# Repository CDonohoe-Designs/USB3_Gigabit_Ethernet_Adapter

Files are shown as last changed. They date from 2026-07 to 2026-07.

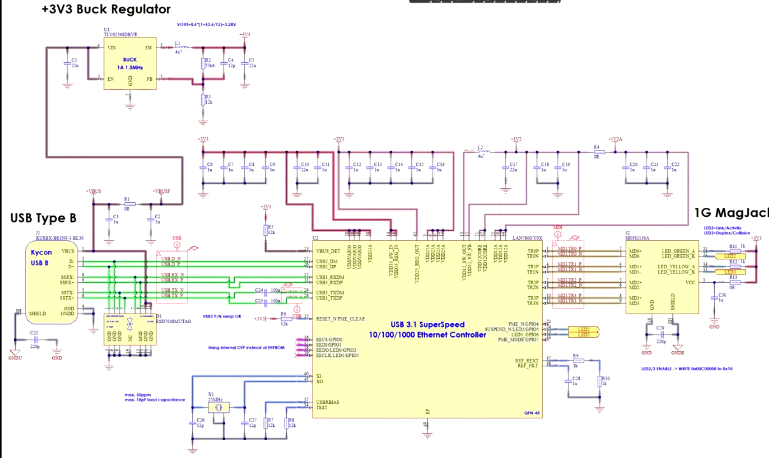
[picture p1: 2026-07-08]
Images/Schematic/Schematic_PMS.PNG

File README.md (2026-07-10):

# USB3 Gigabit Ethernet Adapter

## Project Overview

This repository documents the hardware design and PCB development of a **USB 3.1 Gen 1 to Gigabit Ethernet adapter** based on the **Microchip LAN7800 USB-to-Ethernet controller**.

The project is being developed in **Altium Designer** as a complete hardware design and PCB layout exercise.

The design work includes:

- Schematic capture and hierarchical design structure
- Component selection
- USB 2.0 and USB 3 SuperSpeed interfaces
- Gigabit Ethernet MDI interface
- Power-tree design and decoupling
- ESD protection
- Controlled-impedance PCB routing
- Differential-pair routing and length matching
- PCB design-rule definition
- Design for Manufacture (DFM)
- Design for Test (DFT)
- Manufacturing outputs
- Board bring-up and validation planning

---

## Project Goals

- Design a LAN7800-based USB 3.1 Gen 1 to Gigabit Ethernet adapter in Altium Designer.
- Select and justify the main components used in the design.
- Create a structured schematic covering USB, power, LAN7800, Ethernet, ESD protection, LEDs, reset and test points.
- Implement a four-layer PCB architecture suitable for USB 3 and Gigabit Ethernet routing.
- Define controlled-impedance and differential-pair PCB design rules.
- Route the USB 3 SuperSpeed, USB 2.0 and Gigabit Ethernet interfaces.
- Prepare manufacturing outputs including Gerbers, drill files, BOM, pick-and-place files and schematic PDFs.
- Document the board bring-up and validation process.

---

## Project Documentation

### Schematic

- [LAN7800 USB Ethernet Schematic PDF](Hardware/Altium/LAN7800_USB_Ethernet_RevA/LAN7800_USB_Ethernet_RevA_Schematic.pdf)

### Engineering Documentation

- [Documentation Folder](Docs/)
- [Design Requirements](Docs/01_Design_Requirements.md)
- [Component Selection](Docs/02_Component_Selection.md)
- [PCB Architecture and Stack-Up](Docs/03_PCB_Architecture_and_Stackup.md)

---

## Design Status

| Area | Status |
|---|---|
| Repository structure | Complete |
| Project requirements | Complete |
| Component selection | Complete |
| Schematic design | Complete |
| PCB architecture and stack-up | Complete |
| PCB design rules | Complete |
| Component placement | In progress |
| USB differential-pair routing | In progress |
| Ethernet differential-pair routing | Not started |
| General PCB routing | Not started |
| Manufacturing outputs | Not started |
| Bring-up plan | Not started |

---

## Main IC

**Microchip LAN7800**

USB 3.1 Gen 1 to 10/100/1000 Gigabit Ethernet controller.

The LAN7800 provides the bridge between the USB interface and the Gigabit Ethernet PHY.

---

## Design Sections

The hardware design contains the following main functional areas:

- USB 3.0 Type-B interface
- USB 2.0 D+ / D− interface
- USB 3 SuperSpeed TX and RX differential pairs
- LAN7800 controller
- Gigabit Ethernet MDI interface
- RJ45 connector and magnetics
- USB VBUS input filtering
- 3.3 V power regulation
- LAN7800 2.5 V and 1.2 V supply rails
- 25 MHz crystal and clock circuitry
- Reset and configuration straps
- Ethernet status LEDs
- USB and Ethernet ESD protection
- Power, reset and bring-up test points

---

## PCB Architecture

The design uses a **4-layer PCB stack-up**.

| Layer | Function |
|---|---|
| L1 – Top | Components, USB, Ethernet and critical signals |
| L2 – GND | Continuous high-speed signal reference plane |
| L3 – GND | Secondary continuous ground plane |
| L4 – Bottom | Power distribution and secondary routing |

USB and Ethernet high-speed differential pairs are routed primarily on the Top Layer and referenced to the continuous L2 ground plane.

The PCB design includes controlled-impedance profiles for:

- USB 2.0 — 90 Ω differential
- USB 3 SuperSpeed — 90 Ω differential
- Gigabit Ethernet MDI — 100 Ω differential

---

## PCB Design Rules

The Altium project includes dedicated design constraints for:

- USB 2.0 differential routing
- USB 3 SuperSpeed differential routing
- Gigabit Ethernet differential routing
- Differential-pair clearance
- Pair-to-pair Ethernet spacing
- USB 3 clearance from unrelated signals
- Power-rail trace widths
- Switching-node routing
- Via dimensions
- Annular ring requirements
- Solder-mask expansion
- Solder-mask sliver
- Silkscreen-to-mask clearance
- Differential-pair length matching

The routing constraints and impedance geometry are derived from the implemented Altium four-layer stack-up.

---

## Repository Structure

```text
USB3_Gigabit_Ethernet_Adapter/
│
├── Docs/
│   ├── 01_Design_Requirements.md
│   ├── 02_Component_Selection.md
│   └── 03_PCB_Architecture_and_Stackup.md
│
├── Hardware/
│   └── Altium/
│       └── LAN7800_USB_Ethernet_RevA/
│           ├── 01_USB_B_and_Power.SchDoc
│           ├── 02_LAN7800_Controller.SchDoc
│           ├── LAN7800_USB_Ethernet_RevA.PcbDoc
│           ├── LAN7800_USB_Ethernet_RevA.PrjPcb
│           └── LAN7800_USB_Ethernet_RevA_Schematic.pdf
│
├── Libraries/
├── Assembly/
├── BOM/
├── Gerbers/
├── PDFs/
│
└── README.md

## Project Files

- [View Schematic PDF](Hardware/Altium/LAN7800_USB_Ethernet_RevA/LAN7800_USB_Ethernet_RevA_Schematic.pdf)
- [View Engineering Documentation](Docs/)
- [Browse Altium Design Files](Hardware/Altium/LAN7800_USB_Ethernet_RevA/)

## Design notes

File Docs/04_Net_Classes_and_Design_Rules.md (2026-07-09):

# PCB Net Classes and Design Rules

## 1. Purpose

This document records the electrical, routing and manufacturing constraints applied to the LAN7800 USB 3.1 Gen 1 to Gigabit Ethernet Adapter PCB.

The rules are intended to:

- Control trace widths and clearances
- Apply controlled-impedance routing
- Separate high-speed, power and general-purpose nets
- Control differential-pair geometry
- Define via and board-manufacturing constraints
- Provide traceable engineering evidence for design review

## 2. Rule-Definition Strategy

The PCB will use a hierarchical rule structure.

General rules will apply to the complete PCB, while more-specific rules will override them for:

- USB 2.0
- USB 3.x SuperSpeed
- Gigabit Ethernet MDI
- Power rails
- Crystal circuitry
- General low-speed signals

The most-specific applicable rule will be given the highest priority.

## 3. Planned Net Classes

| Net class | Function |
|---|---|
| `USB2_HS` | USB 2.0 D+ and D− |
| `USB3_SS` | USB 3.x TX and RX differential pairs |
| `ETH_MDI` | Four Gigabit Ethernet MDI pairs |
| `CLOCK_25MHZ` | LAN7800 crystal nets |
| `POWER_VBUS` | USB VBUS and filtered VBUS |
| `POWER_3V3` | 3.3 V digital and analogue rails |
| `POWER_2V5` | LAN7800 internal 2.5 V rail |
| `POWER_1V2` | LAN7800 internal 1.2 V rails |
| `GENERAL` | Remaining low-speed signals |

## 4. Differential-Pair Classes

| Differential-pair class | Members |
|---|---|
| `USB2_DIFF` | USB 2.0 differential pair |
| `USB3_DIFF` | USB 3 TX and RX pairs |
| `ETH_DIFF` | MDI TR0, TR1, TR2 and TR3 pairs |

## 5. Controlled-Impedance Profiles

| Interface | Altium profile | Target |
|---|---|---:|
| USB 2.0 | `D90` | 90 Ω differential |
| USB 3.x | `D90` | 90 Ω differential |
| Gigabit Ethernet | `D100` | 100 Ω differential |

The profiles were calculated using the implemented four-layer stack in Altium Layer Stack Manager.

## Differential-Pair Routing Rules

| Rule | Differential-pair class | Impedance profile | Width | Gap |
|---|---|---|---:|---:|
| `DP_USB3_D90` | `USB3_DIFF` | `D90` | 0.246 mm | 0.127 mm |
| `DP_USB2_D90` | `USB2_DIFF` | `D90` | 0.246 mm | 0.127 mm |
| `DP_ETH_D100` | `ETH_DIFF` | `D100` | 0.184 mm | 0.127 mm |

The preferred width and pair gap are derived from the controlled-impedance profiles in Altium Layer Stack Manager.

## Differential-Pair Clearance Rule

A dedicated clearance rule permits the controlled-impedance gap within each differential pair while maintaining a larger clearance to unrelated copper.

| Rule | Application | Minimum clearance | Priority |
|---|---|---:|---:|
| `CLEARANCE_SAME_DIFF_PAIR` | Members of the same differential pair | 0.127 mm | 1 |
| `Clearance_1` | All other electrical objects | 0.254 mm | 2 |

The differential-pair rule has higher priority than the general board-clearance rule.

## Routing Width Rules

| Rule | Scope | Minimum | Preferred | Maximum |
|---|---|---:|---:|---:|
| `WIDTH_SWITCH_NODES` | `SWITCH_NODES` | 0.40 mm | 0.60 mm | 1.00 mm |
| `WIDTH_VBUS` | `POWER_VBUS` | 0.40 mm | 0.60 mm | 1.00 mm |
| `WIDTH_1V2` | `POWER_1V2` | 0.30 mm | 0.50 mm | 0.80 mm |
| `WIDTH_3V3` | `POWER_3V3` | 0.30 mm | 0.50 mm | 0.80 mm |
| `WIDTH_2V5` | `POWER_2V5` | 0.20 mm | 0.30 mm | 0.50 mm |
| `WIDTH_GENERAL` | All remaining nets | 0.15 mm | 0.20 mm | 0.30 mm |

The values are initial routing constraints. Short power connections may use copper regions where this provides a lower-impedance current path.

## Routing Layer Rules

High-speed and clock nets are constrained to the Top Layer so that they reference the adjacent continuous L2 ground plane and avoid unnecessary layer transitions.

| Rule | Net class | Top Layer | Bottom Layer |
|---|---|---|---|
| `ROUTE_LAYER_USB3` | `USB3_SS` | Allowed | Not allowed |
| `ROUTE_LAYER_USB2` | `USB2_HS` | Allowed | Not allowed |
| `ROUTE_LAYER_ETH` | `ETH_MDI` | Allowed | Not allowed |
| `ROUTE_LAYER_CLOCK` | `CLOCK_25MHZ` | Allowed | Not allowed |
| `ROUTE_LAYER_GENERAL` | All remaining nets | Allowed | Allowed |

The high-speed interfaces will be routed primarily on L1 and referenced to the continuous L2 `GND_1` plane.

## Routing Via Style Rules

| Rule | Scope | Preferred diameter | Preferred hole |
|---|---|---:|---:|
| `VIA_POWER` | Power net classes | 0.80 mm | 0.40 mm |
| `VIA_GENERAL` | All remaining nets | 0.60 mm | 0.30 mm |

The general via provides a 0.15 mm nominal annular ring. Larger power vias are preferred where supply rails change layers. USB, Ethernet and crystal nets are constrained to the Top Layer to avoid unnecessary via transitions.

## Matched-Length Rules

This checks the overall length difference between MDI_TR0, TR1, TR2 and TR3. Microchip allows a maximum delta of 600 mils or 15.24 mm between the four pairs.

Altium uses Within Differential Pair Length for matching the two members of each pair, and Group Matched Lengths for matching complete differential pairs against one another.

| Rule | Scope | Mode | Tolerance |
| --- | --- | --- | ---: |
| `MATCH_USB3_WITHIN_PAIR`  | `USB3_DIFF` | Within differential pair |  0.127 mm |
| `MATCH_ETH_WITHIN_PAIR` | `ETH_DIFF`  | Within differential pair | 1.27 mm |
| `MATCH_ETH_BETWEEN_PAIRS` | `ETH_DIFF`  | Between complete pairs |  15.24 mm |

## Minimum Annular Ring Rule

The minimum annular ring is controlled to maintain sufficient copper around drilled pads and vias.

| Rule | Scope | Minimum annular ring |
|---|---|---:|
| `MIN_ANNULAR_RING` | All pads and vias | 0.15 mm |

The general routing via uses a 0.60 mm diameter and a 0.30 mm hole:

`(0.60 mm − 0.30 mm) / 2 = 0.15 mm`

## Drilled-Hole Size Rule

The drilled-hole rule prevents pads and vias from using hole sizes below the selected manufacturing baseline.

| Rule | Scope | Minimum hole | Maximum hole |
|---|---|---:|---:|
| `MIN_DRILLED_HOLE` | All pads and vias | 0.30 mm | 6.35 mm |

The 0.30 mm minimum matches the general routing-via hole size. The maximum value allows for connector and mechanical mounting holes and will be reviewed against the final footprint set.

## Solder-Mask Expansion Rule

A positive solder-mask expansion is applied around component pads to compensate for solder-mask registration tolerances.

| Rule | Scope | Top expansion | Bottom expansion |
|---|---|---:|---:|
| `SM_EXPANSION_PADS` | All component pads | 0.075 mm | 0.075 mm |

The expansion is measured from the copper-pad edge. Vias are excluded from this rule and will be handled separately through via-tenting settings.

Fine-pitch footprints may use local solder-mask overrides where necessary to maintain acceptable solder-mask slivers.

## Minimum Solder-Mask Sliver Rule

The solder-mask sliver rule controls the minimum remaining strip of solder mask between adjacent mask openings.

| Rule | Scope | Minimum sliver |
|---|---|---:|
| `MIN_SOLDER_MASK_SLIVER` | All solder-mask openings | 0.075 mm |

The value is based on an LDI solder-mask manufacturing process. Fine-pitch components will be reviewed individually during DRC to confirm that the resulting mask geometry is manufacturable.

## Silk-to-Solder-Mask Clearance Rule

The silkscreen clearance rule prevents component outlines, reference
designators and other overlay objects from overlapping exposed pads and
solder-mask openings.

| Rule | Scope | Check mode | Minimum clearance |
|---|---|---|---:|
| `SILK_TO_MASK_CLEARANCE` | All silkscreen objects | Clearance to solder-mask openings | 0.10 mm |

Silkscreen objects will be reviewed after component placement to ensure
that reference designators remain readable and do not extend over exposed
copper, holes or solderable pads.

## Ethernet Pair-to-Pair Spacing

Microchip recommends that the spacing between adjacent Ethernet differential pairs is at least five times the spacing used within one pair.

The controlled-impedance gap within each Ethernet pair is:

0.127 mm

Altium Clearance Rule
| Rule | First object | Second object | Minimum clearance |
| --- | --- | --- | ---: |
| `CLEARANCE_ETH_BETWEEN_PAIRS` | `ETH_DIFF` differential-pair class | `ETH_DIFF` differential-pair class | 0.635 mm |

## USB 3 Spacing from Unrelated Signals

Microchip recommends keeping USB 3 SuperSpeed differential pairs at least five trace widths away from unrelated signals.

The controlled-impedance trace width for the USB 3 differential pairs is: 0.246 mm

Altium Clearance Rule

| Parameter | Setting |
| --- | --- |
| Rule name | `CLEARANCE_USB3_TO_OTHER_SIGNALS` |
| First object | Net Class → `USB3_SS` |
| Second object | Custom Query → `Not InNetClass('USB3_SS')` |
| Minimum clearance | 1.23 mm |

## Remaining Design Rules

Rules not specifically documented in this file retain their Altium default
values during the initial layout.

Additional rules will only be introduced where required by:

- Component placement
- Footprint geometry
- Manufacturer capability
- Signal-integrity constraints
- DRC results
- Design-review findings

This avoids introducing unnecessary constraints before the physical layout
and routing requirements are fully understood.

## 8. Rule Priority

The intended priority order is:

USB3 differential rules
USB2 differential rules
Ethernet differential rules
Crystal rules
Power rules
General routing rules
Global manufacturing rules

## 9. Verification

The rule-definition stage will be complete when:

- All required net classes exist.
- All differential pairs are recognised.
- Controlled-impedance profiles are assigned.
- Rule priorities are reviewed.
- Online DRC is enabled.
- Batch DRC reports no unresolved rule-definition errors.
- Screenshots are stored in the repository.

## 10. Repository Evidence

The following screenshots will be stored in the repository:

- `Images/PCB/02_Impedance_Profiles.png`
- `Images/PCB/03_Net_Classes.png`
- `Images/PCB/04_Differential_Pair_Classes.png`
- `Images/PCB/05_Routing_Rules.png`
- `Images/PCB/06_Rule_Priorities.png`

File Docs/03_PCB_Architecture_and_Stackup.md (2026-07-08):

# PCB Architecture and Stack-Up

## 1. Purpose

This document records the PCB architecture and layer-stack decisions for the LAN7800 USB 3.1 Gen 1 to Gigabit Ethernet Adapter.

The PCB contains:

- USB 3.1 Gen 1 differential pairs
- USB 2.0 differential pair
- Four Gigabit Ethernet MDI differential pairs
- A 25 MHz crystal circuit
- Switching power regulators
- Analogue and digital power rails

The PCB must provide continuous signal-reference planes, controlled-impedance routing and low-impedance power distribution.

## 2. PCB Architecture Decision

**Decision:** Use a four-layer PCB based on Altium Designer's generic four-layer stack.

**Reasons:**

- USB 3 and Gigabit Ethernet require stable signal-return paths.
- Solid ground planes reduce return-path discontinuities and EMI.
- Four layers provide better routing and power distribution than a two-layer PCB.
- The structure supports controlled-impedance differential routing.
- It provides a practical balance between performance, complexity and cost.

The initial layout will use Altium's generic FR-4 material and stack parameters. The exact values can be adjusted later if the design is prepared for manufacture.

## 3. Layer Assignment

| Layer | Name | Primary function |
|---|---|---|
| L1 | TOP | Components, USB and Ethernet differential pairs, critical signals |
| L2 | GND | Continuous solid ground reference plane for L1 |
| L3 | GND | Continuous solid ground reference plane for L4 |
| L4 | BOTTOM | Power distribution, low-speed signals and secondary routing |

## 4. Layer-Use Rules

- Route USB and Ethernet differential pairs primarily on L1.
- Reference L1 high-speed signals directly to the L2 ground plane.
- Keep L2 continuous beneath USB, Ethernet and crystal-related signals.
- Keep L3 as a continuous ground plane.
- Use L4 for power rails and non-critical signals.
- Use short, wide tracks or copper regions for power distribution.
- Avoid routing high-speed signals across plane gaps or voids.
- Avoid layer changes on USB and Ethernet differential pairs.
- Connect L2 and L3 using ground stitching vias.
- Add ground copper on the outer layers where routing permits.

## 5. Controlled-Impedance Requirements

| Interface | Target differential impedance |
|---|---:|
| USB 2.0 D+ / D− | 90 Ω |
| USB 3 TX+ / TX− | 90 Ω |
| USB 3 RX+ / RX− | 90 Ω |
| Gigabit Ethernet MDI pairs | 100 Ω |

The final track width and pair separation will be calculated using Altium Layer Stack Manager.

The values will depend on:

- Copper thickness
- Dielectric thickness
- Dielectric constant
- Routing layer
- Distance to the reference plane

Track width and pair gap will not be selected by guesswork.

## 6. Altium Impedance Profiles

The following impedance profiles will be created in:

`Design → Layer Stack Manager → Impedance`

| Profile name | Type | Target |
|---|---|---:|
| `USB_90R_DIFF` | Differential | 90 Ω |
| `ETH_100R_DIFF` | Differential | 100 Ω |

Primary routing configuration:

Routing layer: L1 Top
Reference layer: L2 GND

## 7. Grounding Architecture

The PCB will use one common digital ground plane on L2.

Separate schematic net names such as:

- `USB_SHIELD`
- `RJ45_SHIELD`
- `GND`

are used to document different EMC functions. The connector shields will connect to circuit ground only through their defined coupling networks.

The LAN7800 exposed pad and all local ground connections will connect to the solid L2 ground plane using short connections and multiple ground vias.

## 8. Power-Distribution Architecture

The principal PCB power rails are:

- `VBUS`
- `VBUSF`
- `+3V3`
- `+3V3_A`
- `+2V5`
- `+1V2`
- `+1V2_A`

Power distribution will primarily use copper regions or short, wide tracks on L3 and the outer layers.

The following areas require compact placement and routing:

- USB VBUS ferrite filter
- TLV62568 3.3 V regulator
- LAN7800 internal 1.2 V regulator loop
- LAN7800 analogue-rail ferrite filters
- Local decoupling capacitors

## 9. Mechanical Architecture

The intended signal flow is:

`USB Type-B → ESD protection → LAN7800 → RJ45 MagJack`

Initial placement principles:

- USB Type-B and RJ45 connectors at board edges.
- ESD protection immediately beside the USB connector.
- LAN7800 positioned between USB and Ethernet interfaces.
- Crystal and load capacitors beside the LAN7800 XI/XO pins.
- Switching regulators kept away from the crystal and high-speed differential pairs.
- Decoupling capacitors placed beside their associated supply pins.

## 10. ## Implemented Layer Stack

| Layer | Material/type | Thickness | Function |
|---|---|---:|---|
| Top solder mask | Solder resist | 0.010 mm | Surface protection |
| L1 Top | 1 oz copper | 0.035 mm | Components and critical signals |
| Prepreg | IS400, Dk 4.2 | 0.200 mm | L1-to-L2 dielectric |
| L2 GND_1 | 1 oz copper | 0.035 mm | Primary reference plane |
| Core | IS400, Dk 4.4 | 1.010 mm | Central dielectric |
| L3 GND_2 | 1 oz copper | 0.035 mm | Secondary reference plane |
| Prepreg | IS400, Dk 4.2 | 0.200 mm | L3-to-L4 dielectric |
| L4 Bottom | 1 oz copper | 0.035 mm | Power and secondary routing |
| Bottom solder mask | Solder resist | 0.010 mm | Surface protection |

-Nominal laminate and copper thickness: 1.55 mm.  
-Approximate finished thickness including solder mask: 1.57 mm.
-Based on Euro Circuits process
=======

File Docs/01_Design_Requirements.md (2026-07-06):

# Design Requirements

## Project Title

USB3 Gigabit Ethernet Adapter

## Objective

Design a USB3.1 Gen 1 to Gigabit Ethernet adapter based on the Microchip LAN7800 USB-to-Ethernet controller.

The project is being developed in Altium Designer and documented as a complete hardware design exercise, including schematic capture, component selection, PCB layout planning, design-rule setup, manufacturing outputs, and board bring-up planning.

## Project Scope

This project covers the hardware design of a compact USB3-to-Gigabit-Ethernet adapter. The design will include the USB interface, LAN7800 controller circuitry, Ethernet interface, power regulation, ESD protection, clocking, status LEDs, test points, PCB layout, and manufacturing documentation.

Firmware and driver development are outside the current scope. The adapter is expected to use standard operating system support for the LAN7800 device where available.

## Main Functional Requirements

| Requirement | Description |
|---|---|
| USB interface | USB3.1 Gen 1 upstream interface operating up to 5 Gbps |
| Ethernet interface | Gigabit Ethernet downstream interface |
| Main controller | Microchip LAN7800 USB-to-Ethernet controller |
| Power source | Bus-powered from USB VBUS |
| Power regulation | On-board regulators for LAN7800 supply rails |
| Clock source | 25 MHz clock source for LAN7800 |
| Ethernet connector | RJ45 connector with integrated or external magnetics |
| ESD protection | ESD protection on USB and Ethernet external interfaces |
| Status indication | LEDs for link, activity, and speed indication where supported |
| Reset/configuration | Reset and configuration strap support |
| Test access | Test points for power rails, reset, clock, and bring-up signals |

## USB Interface Requirements

- Use a USB3.1 Gen 1 capable connector.
- Support USB SuperSpeed differential pairs.
- Include suitable ESD protection on USB data lines.
- Route USB3 differential pairs with controlled impedance.
- Keep USB3 pair routing short, direct, and length-conscious.
- Maintain solid ground reference under high-speed USB signals.
- Avoid stubs and unnecessary vias on high-speed USB routing where practical.

## Ethernet Interface Requirements

- Support 10/100/1000 Mbps Ethernet operation.
- Use an RJ45 connector with suitable magnetics.
- Route Ethernet MDI pairs as controlled, length-conscious differential pairs.
- Keep Ethernet pair routing symmetrical and away from noisy switching nodes.
- Include appropriate Bob Smith termination or magnetics-side termination if required by the selected connector/reference circuit.
- Provide Ethernet-side ESD protection where appropriate.

## Power Requirements

- The board shall be powered from USB VBUS.
- Generate all required LAN7800 supply rails on-board.
- Provide adequate bulk and local decoupling.
- Place decoupling capacitors close to the relevant LAN7800 power pins.
- Keep switching regulator loops compact.
- Keep noisy power switching areas away from USB3 and Ethernet differential pairs.
- Provide test points for key power rails.

## Clocking Requirements

- Provide a 25 MHz clock source suitable for the LAN7800.
- Place the crystal or oscillator close to the LAN7800.
- Keep crystal traces short and symmetrical.
- Avoid routing high-speed or noisy signals close to the clock circuit.
- Follow the selected crystal or oscillator datasheet recommendations.

## PCB Requirements

| Item | Requirement |
|---|---|
| PCB layers | 4-layer PCB preferred |
| Grounding | Solid ground reference plane |
| High-speed routing | Controlled-impedance routing for USB3 and Ethernet differential pairs |
| Power routing | Low-impedance power distribution with local decoupling |
| Manufacturability | Suitable for low-volume PCB manufacture |
| Testability | Bring-up test points included |
| Assembly | Components selected with practical package sizes where possible |

## Proposed PCB Stack-Up

A 4-layer stack-up is preferred:

| Layer | Function |
|---|---|
| L1 | Components and high-speed signals |
| L2 | Solid ground plane |
| L3 | Power distribution and secondary routing |
| L4 | Secondary signals and low-speed routing |

## Design-for-Test Requirements

The design should include test points for:

- USB VBUS
- Main regulated power rails
- Ground
- Reset
- LAN7800 clock check point, if practical
- LED/status signals, if useful
- Any enable pins for regulators
- Key configuration strap pins, if useful during bring-up

## Design-for-Manufacture Requirements

- Use practical component packages for hand inspection and low-volume assembly.
- Avoid unnecessarily small passive components unless required for layout.
- Maintain clear silkscreen markings for connectors, LEDs, test points, and polarity-sensitive components.
- Use consistent reference designators.
- Generate Gerbers, drill files, BOM, pick-and-place, and schematic PDFs.
- Run schematic validation and PCB DRC before manufacturing output release.

## Documentation Requirements

The repository should include:

- Design requirements
- Component selection notes
- Power-tree notes
- USB3 and Ethernet layout notes
- Schematic review checklist
- PCB review checklist
- Bring-up and validation test plan
- Manufacturing output folders
- Images of schematic, PCB layout, and 3D view

## Out of Scope

The following are not part of the initial project scope:

- Custom firmware development
- Driver development
- Enclosure design
- EMC pre-compliance testing
- Production test fixture design
- Mass-production release package

These may be added later if the project is extended.

## Initial Design Status

| Area | Status |
|---|---|
| Repository structure | Complete |
| Design requirements | Complete |
| Component selection | Not started |
| Schematic design | Not started |
| PCB layout | Not started |
| Design rules | Not started |
| Manufacturing outputs | Not started |
| Bring-up plan | Not started |

## Next Steps

1. Select the USB connector type.
2. Confirm LAN7800 variant and package.
3. Define the power tree.
4. Select RJ45/magnetics solution.
5. Select USB and Ethernet ESD protection devices.
6. Create the Altium project shell.
7. Start schematic capture.

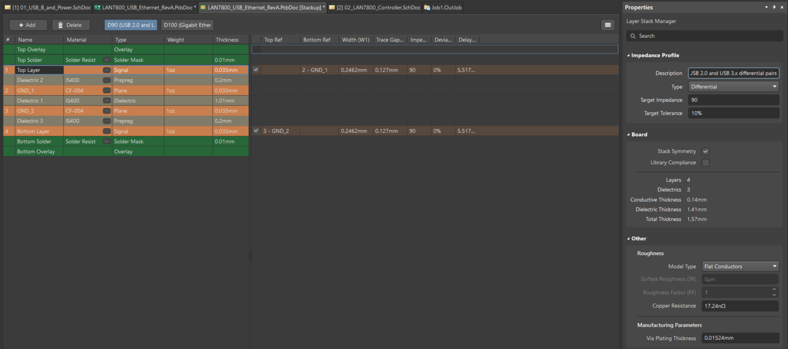
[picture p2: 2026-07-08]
Images/PCB/02_Impedance_Profiles.png

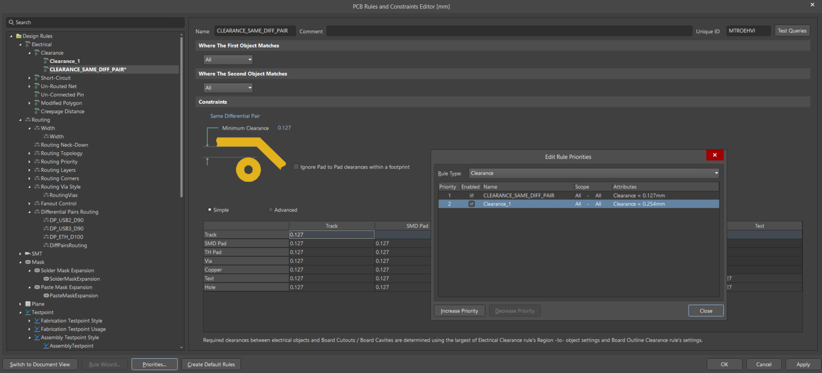
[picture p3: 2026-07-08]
Images/PCB/06_Clearance_Rule_Priorities.png

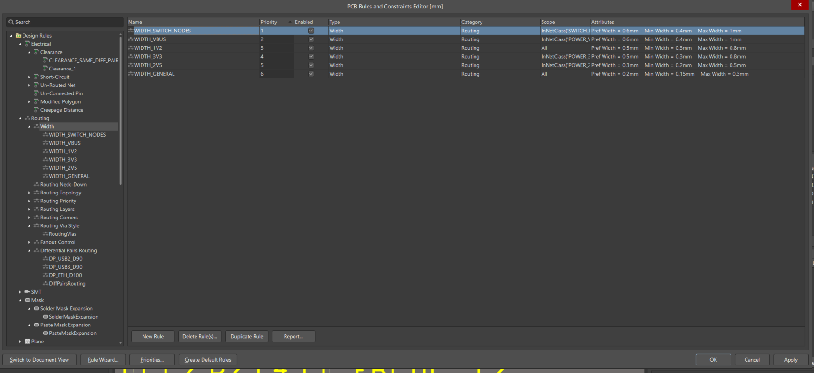
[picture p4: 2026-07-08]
Images/PCB/07_Routing_Width_Rules.png

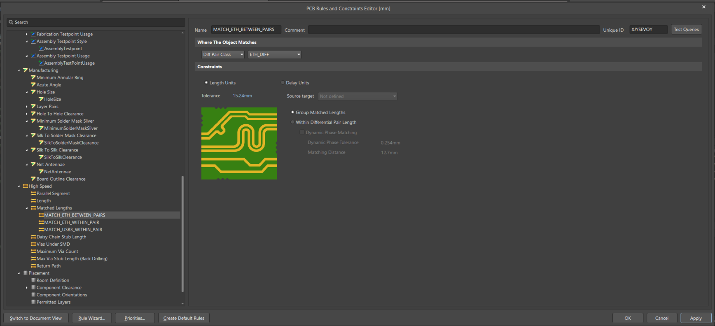
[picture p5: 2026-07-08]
Images/PCB/10_Matched_Length_Rules.png

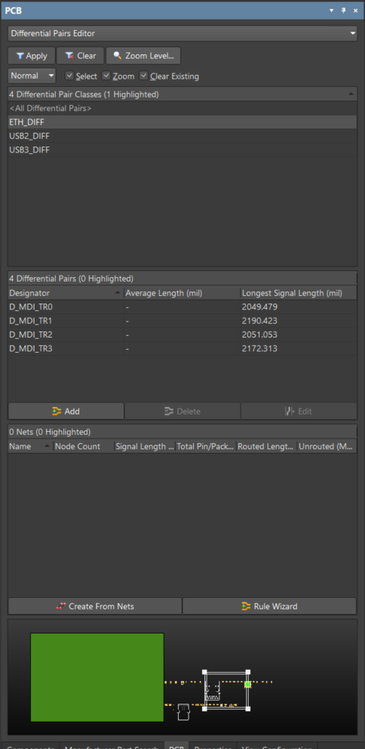
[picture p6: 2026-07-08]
Images/PCB/04_Differential_Pair_Classes.png

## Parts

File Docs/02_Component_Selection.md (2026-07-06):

# Component Selection

## Purpose

Record the main component choices for the LAN7800 USB3 Gigabit Ethernet Adapter.

## Selection Criteria

Components will be selected based on:

- Electrical suitability
- Datasheet support
- Availability
- Practical footprint
- Low-volume assembly suitability
- 4-layer PCB compatibility

## Main Component Summary

| Function | Proposed Choice | Status |
|---|---|---|
| USB-to-Ethernet controller | Microchip LAN7800 | Selected |
| USB connector | USB-C receptacle | Planned |
| Ethernet connector | RJ45 with integrated magnetics | TBD |
| USB ESD protection | Low-capacitance USB3 ESD device | TBD |
| Ethernet ESD protection | Gigabit Ethernet ESD device | TBD |
| Power regulation | Buck / LDO regulators | TBD |
| Clock source | 25 MHz crystal or oscillator | TBD |
| LEDs | Link / activity / speed LEDs | TBD |
| Test points | SMT test pads | Planned |

## Key Design Notes

- LAN7800 is the main USB3.1 Gen 1 to Gigabit Ethernet controller.
- USB-C is preferred for a modern compact adapter design.
- RJ45 with integrated magnetics is preferred to simplify layout.
- USB3 and Ethernet interfaces require suitable low-capacitance ESD protection.
- Power rails and current budget must be confirmed from the LAN7800 datasheet.
- A 25 MHz clock source is required.
- Test points should be added for VBUS, power rails, reset, enables, and useful bring-up signals.

## Next Actions

1. Confirm LAN7800 package.
2. Select USB-C connector.
3. Select RJ45 MagJack.
4. Select USB and Ethernet ESD devices.
5. Define the power tree.
6. Select the 25 MHz clock source.
7. Add manufacturer part numbers.

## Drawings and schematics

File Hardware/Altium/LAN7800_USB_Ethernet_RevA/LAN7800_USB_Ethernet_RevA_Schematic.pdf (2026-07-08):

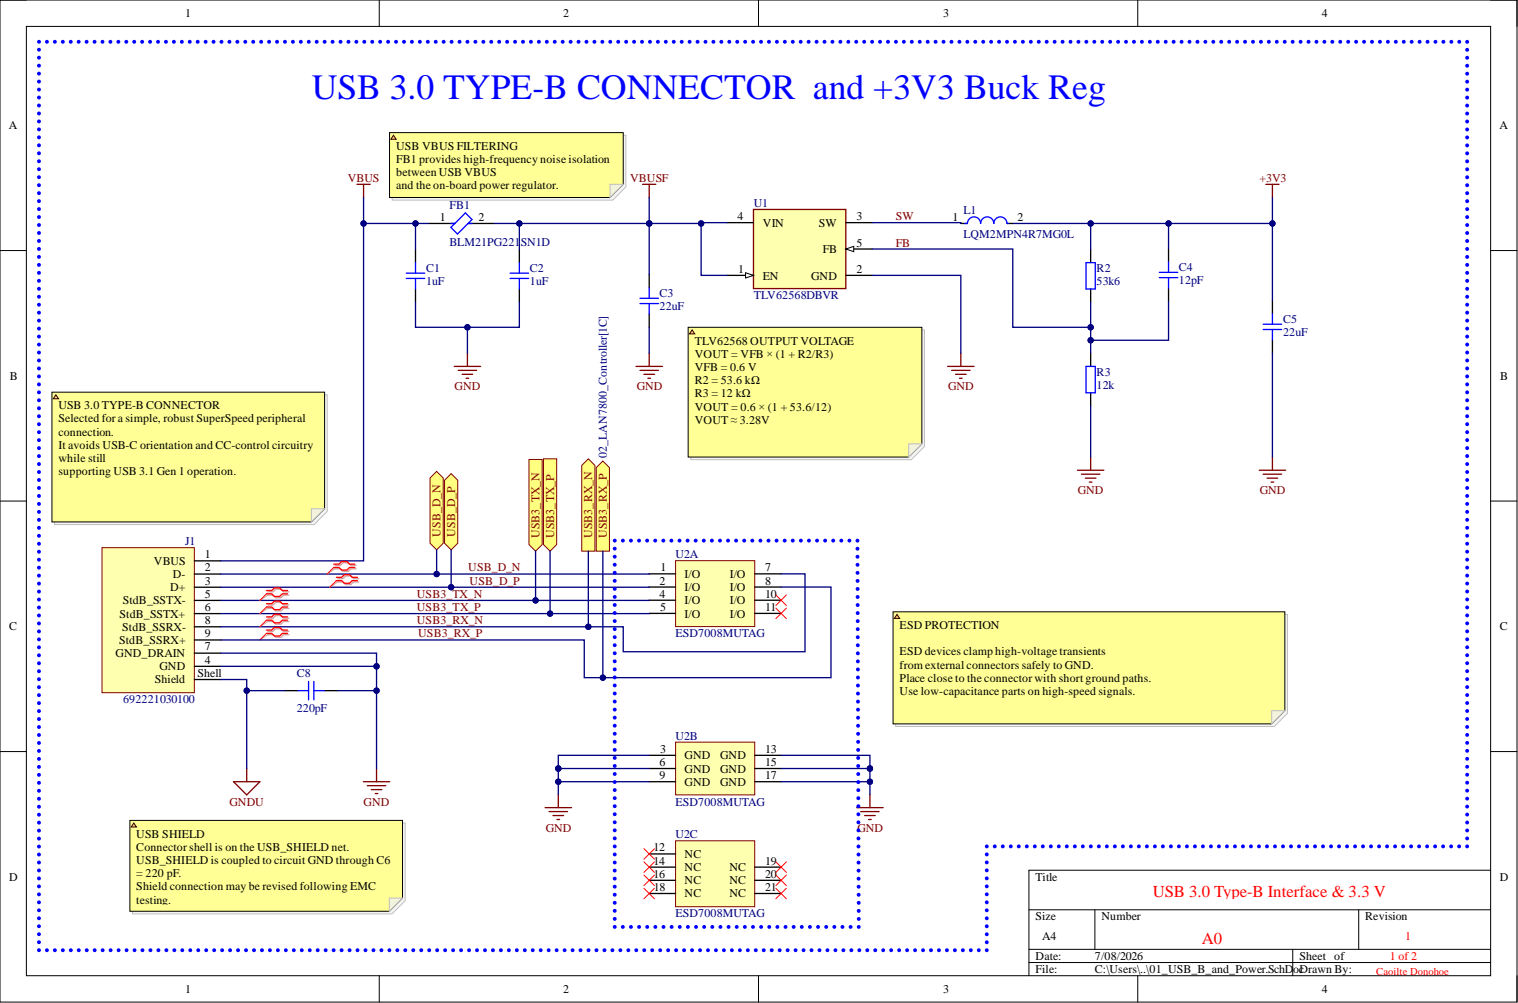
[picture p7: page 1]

USB 3.0 TYPE-B CONNECTOR and +3V3 Buck Reg

3 | USB_ D _P | | 2 | 8
5 USB3 _ T X_N | | | 4 | 1 0
6 USB3 _ T X_P | | | 5 | 1 1
8 USB3 _RX _N
9 USB3 _RX _P | | ESD 7 0 0 8MU TA

6 | 1 5
9 | 1 7

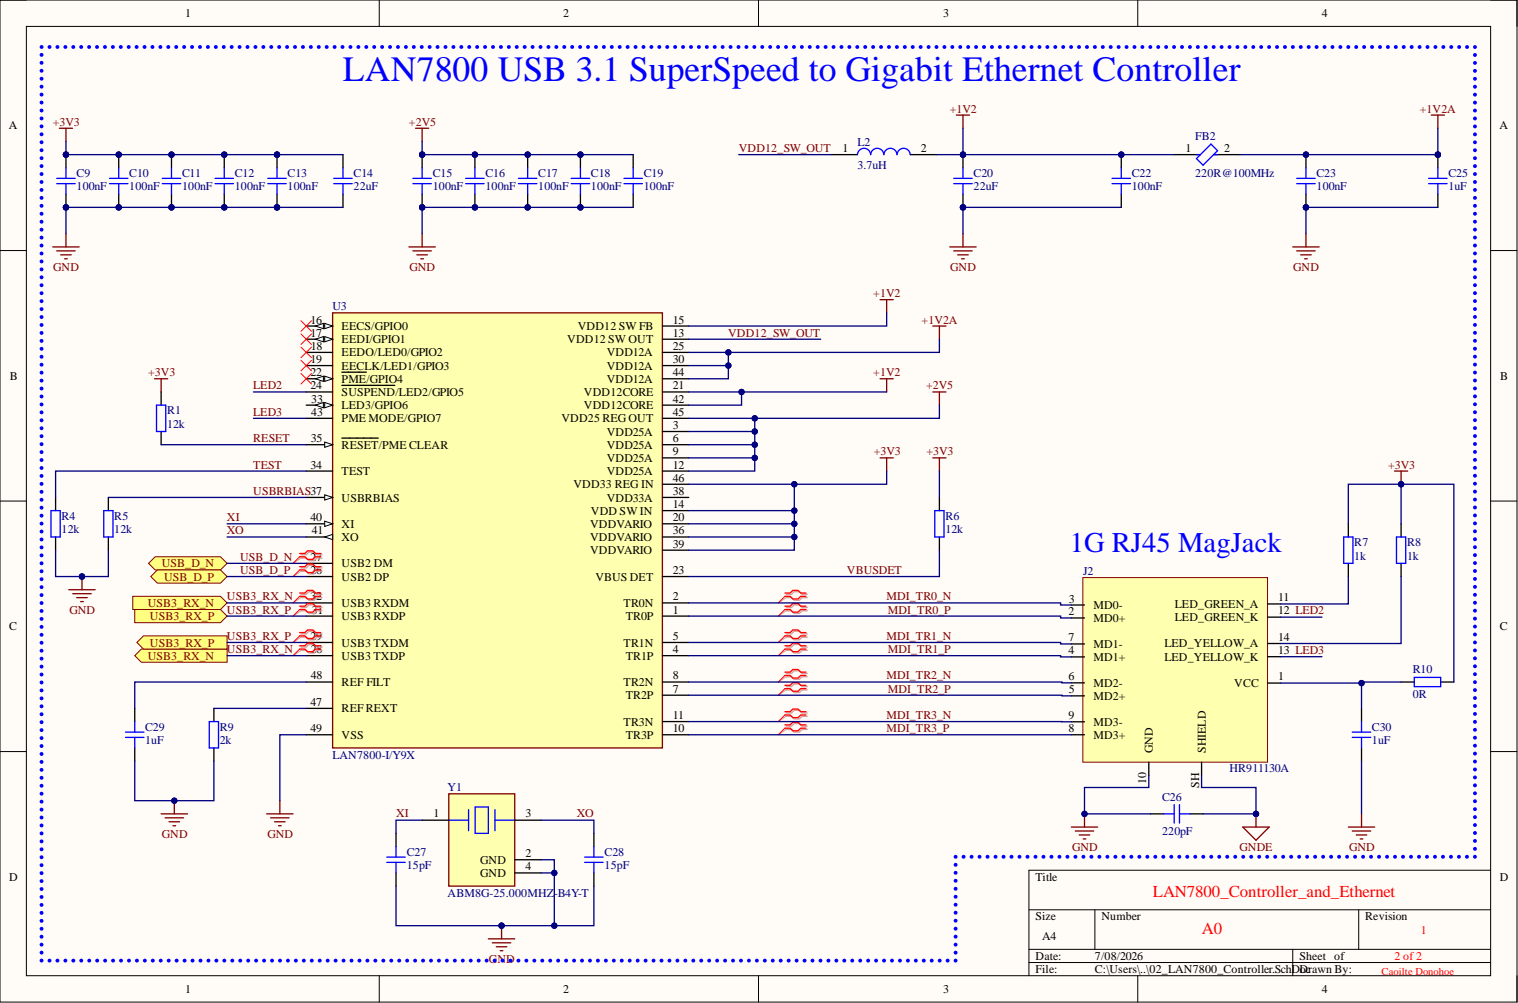
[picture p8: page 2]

LAN7800 USB 3.1 SuperSpeed to Gigabit Ethernet Controller

USBRBIAS | USBRBIAS 37

VBUSDET

USB3 RXDM 32 | MDI_TR0_N | MD0+ 2 MD0- 3 LED_GREEN_K LED_YELLOW_K VCC
USB3 RXDP 31 | MDI_TR0_P | | | 12 LED2

USB3 TXDM 29 | MDI_TR1_N | MD1- 7
USB3 TXDP 28 | MDI_TR1_P | MD1+ 4 | 13 LED3 1

REF FILT 48 | MDI_TR2_N
REF REXT 47 | MDI_TR2_P | MD2+ 5 MD2- 6

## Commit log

2026-07-08 Creation Of Schematics
    [01_USB_B_and_Power.SchDoc, 01_USB_C_and_Power.SchDoc, 02_LAN7800_Controller.SchDoc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]
2026-07-08 added .md for eng designs
    [LAN7800_USB_Ethernet_RevA.PrjPcb]
2026-07-08 additional info for PCB architecture and stackup
2026-07-08 Impedance profiles created for USB and Ethernet
    [LAN7800_USB_Ethernet_RevA.PcbDoc]
2026-07-08 Added net classes png evidence
    [02_LAN7800_Controller.SchDoc, LAN7800_USB_Ethernet_RevA.PcbDoc]
2026-07-08 Differential_Pair_Classes evidence
    [LAN7800_USB_Ethernet_RevA.PcbDoc]
2026-07-08 updated differential pair routing rules
    [LAN7800_USB_Ethernet_RevA.PcbDoc]
2026-07-08 Routing Width Rules included and image of evidence
    [LAN7800_USB_Ethernet_RevA.PcbDoc]
2026-07-08 Update 04_Net_Classes_and_Design_Rules.md with Drilled hole size rules
2026-07-08 Update 04_Net_Classes_and_Design_Rules.md with Solder mask expansion rule
2026-07-08 Update 04_Net_Classes_and_Design_Rules.md with Minimum Solder-Mask Sliver Rule
2026-07-08 Update 04_Net_Classes_and_Design_Rules.md with Silk-to-Solder-Mask Clearance Rule
2026-07-09 Update 04_Net_Classes_and_Design_Rules.md Ethernet to other traces rule
2026-07-09 Update 04_Net_Classes_and_Design_Rules.md ethernet to unrelated traces rule
